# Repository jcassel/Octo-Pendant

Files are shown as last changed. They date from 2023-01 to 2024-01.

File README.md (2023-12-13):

# Octo Pendant
SplashMD_v1 0 0 16
An OctoPrint remote API pendant touch screen. An alternate touch UI for when you are at your printer but want to ensure constant control from OctoPrint. Also includes some utilities to make leveling your printer a little easier. This is really handy for anyone that runs a print farm and wants quick local control of a printer that might be getting run from a multi instance deploy of Octoprint.  It’s so much faster to just tap tap tap for a couple of things than to go to a terminal and access the right instance. One might also find it useful if you are running a headless printer. 

## Features:
* Connects to OctoPrint though API. 
* Displays running Job Status. 
* Allows control of running Job.
  * Can start, pause/resume, and stop loaded files.
* Can control Axis movement.
* Can control Tool and bed temperatures.
* Can run mesh leveling 
* Includes a utility for Manual bed leveling

Currently there are 5 TFT display screens and 3 web configuration screens. 
  TFT Screens include: Main/Monitor, Axis Control, Temperature Control, Leveling Utility, and Info.
  
  Web Configuration Screens include: Configuration Settings, Uploads (File Management), and Firmware Update (OTA)

## Parts

**Required**
* Wemos D1 Mini (4M) [Amazon](https://www.amazon.com/dp/B073CQVFLK/) or [AliExpress](https://www.aliexpress.us/item/3256803535819463.html) or [Tindie](https://www.tindie.com/stores/jcsgotthis/)
* 2.4" Touch TFT (ILI9341) Or equivalent [AliExpress](https://www.aliexpress.us/item/2251832829271342.html) or [Amazon](https://www.amazon.com/dp/B09XHRKFMM) or [Tindie](https://www.tindie.com/stores/jcsgotthis/)
* USB Cable for programing and power 

**nice to have**
* TFT to D1 carrier board [Tindie](https://www.tindie.com/stores/jcsgotthis/)

## Setup
Once you have compiled and downloaded the Firmware, you will be greeted by the touch calibration screen. Go ahead and calibrate it by touching the screen in each corner as indicated by the screen. 

Now you should see a screen with some text and dashes in a bright yellow on a black back ground. Each screen is composed of a background image and a button coordinate system for checking if you touched something interesting on the screen.

At the bottom of the screen you should see text that says "No File Loaded" Touch this. This will take you to the info screen. Its not got anything interesting on it yet but if you get to that screen, you will know things are generally going to work. 

Next you have a choice on how you load the data files. You can either use the "ESP Sketch data upload tool" or you can connect to the device over Wi-Fi and upload the needed files in to 
the spiffs.  

Using the Data upload tool is the quickest if you have it installed. But if you don’t have it installed, its not hard to just upload everything manually. 

To upload the files manually, (my preferred method) do the following. 

* Using your phone or any PC with a Wi-Fi connection, connect to the new Wi-Fi Access point with a name starting with “OctoPendant-New". 
    * Username: admin 
	* Password: Password1 (this is just the default starting point; yes you can change this in the interface.) 
* Once connected, open a browser and connect to this address:
	http://192.168.4.1/spiffs
	You will need to put in the username and password again. 
	
* On this screen you can select files to upload to the device. Best results are if you upload everything in the /data folder in the following order. Note: there are 11 files.
	* style.css
	* scripts.js
	* spiffs.htm (After this the web interface will become a little better)
	Try to refrain from testing hte other menu items, they are not uploaded yet and you will not get what you want.
	* ota.htm
	* mansettings.js
	* mansettings.htm
	* Control1.bmp
  	* ControlMenu.bmp	
   	* Home.bmp
	* Level.bmp
	* Temps.bmp

 * Next you should load up the json region files. These tell the systen where to look for touch screen events. They are also adjustable if you find you want to move things or adjust the touch regions.
   	* ctlmnuscrn.json
	* ctlscrn.json
	* fSrgn.json
	* hscrn.json
	* infoscrn.json
    	* lvlscrn.json
   	* tmpscrn.json

* Now that everything is loaded, you can use the menu in the web interface to go to the Configuration screen. (First menu item at the top of the web page) 
* on this screen, much of it should be self-explanatory but I will go through it in detail. 
    * At the very top is a button to start a scan for available Wi-Fi signals. Push that button to start it. It will return a list of available SSIDs. 
    * Enter in the Wi-Fi SSID for the network your OctoPrint printer is on. 
    * Enter the Password for that SSID (yes, its clear text).
    * Unit Name: This is the network name or host name of the device as it would show up when registering for DNS or DHCP.
    * You can leave the next 2 at default.. They should just work as is, although I have seen good results with 2000 for delay.
    * The Access Password is the password to gain access to the web pages you are using. You can change it. If you forget it, you can change it through serial connection. 
    * HA Unique Id, is specifically for referencing the device in home assistant and even then it's value is only reference. Best practice is to make it match your Unit Name unless you know why you are changing it. 
    * Enable MQTT this will have the device connect to an MQTT broker and send status updates. *Note: This works and will send a general online status to your MQTT broker but I have not really fleshed out any real capabilities in this area yet.)*
    * MQTT Server: The IP Or Full DNS for your MQTT Broker. Cannot be blank if MQTT is enabled. 
    * MQTT UserName: Username for the connection to the MQTT Broker can be blank even if MQTT is enabled.
    * MQTT Password: Password for the connection to the MQTT Broker Can be blank even if MQTT is enabled.
    * MQTT Port: Must be an int value (0 is valid if MQTT is not enabled), typically 1883 
    * OctoPrint URL: The IP or URL for your OctoPrint instance. 
    * OctoPrint Port: The port for your OctoPrint instance. (5000 is the default)
    * OctoPrint APIKey: A key generated by OctoPrint. I strongly suggest you create a user and an API key just for this device. 
    * Enable Mesh Bed Leveling: Only enable this if you have followed the (Mesh Bed leveling guide in the Guides folder)
    * OctoPrint Level GCode File?: This is the path to the gcode file you will create when following the MeshBedLeveling Guide) 
    * Reload Model?: Is only available when Mesh bed leveling is enabled. If checked, and bed leveling is evoked using the green Running man button, if a model other than the "OctoPrint Level GCode file:" is loaded it will reload it after it completes the Mesh level process. 
    * Start Model?: Is is only available when Mesh bed leveling is enabled. If checked, and bed leveling is evoked using the green Running man button and the "Reload Model button is checked as well, OctoPendant will start the print process for the reloaded model. 
    * Bed Volume X in mm: Fill this in with your printers print volume in the X axis.
    * Bed Volume Y in mm: Fill this in with your printers print volume in the Y axis.
    * Bed Volume Offset in mm: This and the 2 other Volume settings are used for manual bed leveling Utility screen where they are used to calculate the locations for the 5 probe/test points are located. Offset is how far from the edge. 
    * Auto Zero X,Y,Z axis on level screen entry: Recommend that this is checked for machines that don’t do mesh leveling. It will ensure marlin knows where it is before you start a manual bed level process. If you do not Zero all, you could crash your hot end. 
    * Time Zone OffSet hrs: Negative or positive number for your time zone. See this [list](https://www.timeanddate.com/time/zones/) for offset values. Do not include the (+) for Positive values.
 
## TFT Screens

**Main/Monitor**
- Using the top 3 buttons you can navigate to 3 other screens. 
    - Axis Control
    - Leveling Util
    - Temperature control
- In the middle of the screen is general information about the gcode model loaded by OctoPrint. 
    -  Status:  General status of the OctoPrint instance (Printer too).
    -  File: Name of the loaded file,  if there is one.
    -  Uploaded: Date time when the loaded file was uploaded.
    -  Print time Est: Estimated duration hh:mm:ss for the loaded file. 
    -  Print Time: How long has the current print been printing hh:mm:ss
    -  Print Time Left: How much time does OctoPrint estimate is left to complete the current print.
- The lower 3 buttons are for control of the loaded model; Start, Pause, and Stop.
- At the bottom center there is a general status Text this will change dependent on the printers overall status as well as if you have given it a command from the above list. Additionally, If you tap this, it will take you to the info screen. 
HomeScreenMD_v1 0 0 16
***

**Axis Control**
- The green left pointing arrow at the top takes you back to the main screen.
- Standard X,Y,Z Axis controls. You can also turn the motors on or off as well as the cooling fan. 
- Home buttons work independently.
- The value buttons can be used to select a value for relative movement of the selected Axis motion button. 
    - OctoPrint will cache the commands so pressing an arrow several times will produce multiple moves. 
    - Note that not all printers will support the Fan on off action. Think Printers that only have one fan like the Kingroon KP3.
AxisControlMD_v1 0 0 16
***

**Temperature Control**
- The green left pointing arrow at the top takes you back to the main screen.
- Control the temperature of the Build plate and the Extruder with ease. Select presets or use incremental values to get it right where you want it. 
    - Top section of the screen is for controlling the Extruder (hot end) temperature.
        - At the top right of the section, the hot end temperatures are shown as [ actual / setting ]
        - Selecting a top value buttons like 1, 5, 10, 20 set the increment for the (+) and (-) Buttons.
        - Selecting bottom values buttons like 170,180,200,230 set the value selected into the set box. 
        - Pushing the Red Power button will turn off the heat to the hot end. 
        - Pushing the Green enter button will set the value selected in the center setting box. 
    - Bottom section of the screen is for controlling the build plate(print bed) temperature.
        - At the top right of the section, the Print bed temperatures are shown as  [ actual / setting ]
        - Selecting a top value buttons like 1, 5, 10, 20 set the increment for the (+) and (-) Buttons.
        - Selecting bottom values buttons like 50, 60, 70, 100 set the value selected into the set box. 
        - Pushing the Red Power button will turn off the heat to the print bed. 
        - Pushing the Green enter button will set the value selected in the center setting box. 
TemperScreenMD_v1 0 0 16

***
**Bed Leveling Utility** (This screen is still in progress)
Controls for doing a manual bed level as well as sending a command set to do a mesh collection process that works with the [Bed Visualizer plugin for Octoprint](https://github.com/jneilliii/OctoPrint-BedLevelVisualizer). 
- The green left pointing arrow at the top takes you back to the main screen.
    - Settings in the Web interface have an effect on how this screen works. See the Setup section and Guides for level Utility usage.  
- Pressing the Home Button on this screen will home X,Y,Z axis *(see web interface for settings related to homing settings)*
- Pressing one of the 5 dots on the bed will send the print head to that position on your build plat for paper style leveling. Z height will be absolute zero. *(Be sure you have homed your machine prior to using this screen.)*  
- Pressing the Running man on the left (white) will run the mesh collection process and wait. *(see web interface for settings related to mesh leveling settings)*
- Pressing the Running man on the right (green) will run the mesh collection process and reload the current model and start it. *(see web interface for settings related to mesh leveling settings)*

LevelMD_v1 0 0 16

***
**Pendant Info Screen**
This screen shows Connection details for the Pendant. Also has a reset button at the bottom. I plan on adding more here as it makes sense.

InfoScreenMD_v1 0 0 16
***

## Carrier Board
I created a Carrier board for connecting the D1 mini to the 2.4" TFT(Touch) board. Note that the TFT has an SD Card slot on it but it is not wired up. Yes it looks like it is.. The posts are there for support. You can solder these boards together and that saves a lot of space but be careful, the SD card cover is right over 2 of the pins of the D1 mini. 

grbl files are available as part of the repo. Also boards are available from my [Tindie](https://www.tindie.com/stores/jcsgotthis/) Store along with other related items.

D1 mini mounted on carrier*(Note that I have a small Cap to help stabilize power for the board. It’s not really needed.):

TFT-esp8266CarrierBoard_D1

Carrier without D1 mini:

TFT-esp8266CarrierBoard_Back

TFT mount side:

TFT-esp8266CarrierBoard_Front

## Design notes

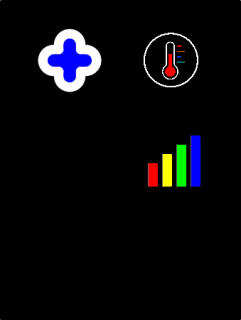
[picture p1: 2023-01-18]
ControlMenu.bmp

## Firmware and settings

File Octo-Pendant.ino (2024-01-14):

#include <ArduinoJson.h> 
#include <ESP8266WiFi.h>
#include <ESP8266WebServer.h>
#include <ESP8266mDNS.h>
#include <Bounce2.h>
#include <NTPClient.h>
#include <MQTT.h>
#include "TimeRelease.h"
#include "ActionRegion.h"
#include <OctoPrintAPI.h> //would be best to use this fork: https://github.com/jcassel/OctoPrintAPI but the parent at https://github.com/chunkysteveo/OctoPrintAPI should work as well. 
#include <SPI.h>
#include <TFT_eSPI.h>      // Hardware-specific library
#include "globals.h"
#include "MQTTControl.h"
#include <ESP8266WebOTA.h> //Lib is here: https://github.com/jcassel/ESP8266WebOTA
#include "FS.h"
#define FS_NO_GLOBALS
#include "webPages.h"

#include <Time.h>         //We will need these two just to do some rough time math on the timestamps we get
#include <TimeLib.h>

void setup() {
  Serial.begin(74880);
  #ifdef _debugopra
  Serial.println("Begin Setup");
  
  struct  rst_info  *rtc_info = system_get_rst_info();
  os_printf("reset  reason: %x\n",  rtc_info->reason);
  Serial.println(rtc_info->reason);
   if (rtc_info->reason ==  REASON_WDT_RST  || rtc_info->reason ==  REASON_EXCEPTION_RST  || rtc_info->reason ==  REASON_SOFT_WDT_RST)  {
     if (rtc_info->reason ==  REASON_EXCEPTION_RST) {
       os_printf("Fatal exception (%d):\n", rtc_info->exccause);
      }
      //The address of  the last  crash is  printed,  which is  used  to debug garbled output.
     os_printf("epc1=0x%08x,  epc2=0x%08x,  epc3=0x%08x,  excvaddr=0x%08x,depc=0x%08x\n",rtc_info->epc1,  rtc_info->epc2, rtc_info->epc3, rtc_info->excvaddr,  rtc_info->depc);
   }
  #endif
  
  #ifdef _OctoAPIDebug
  api._debug = true;
  #endif
   
  InitStorageSetup(); //start spiffs
  SetupWifi();
  
  loadSettingsConfig();
  loadMQTTConfig();

  Serial.println("begin init pages");
  initialisePages();
  Serial.println("end init pages");
  webServer.begin();
  Serial.println("end webserver.begin");
  
  ESP8266webota.init(&webServer,"/update","admin",wificonfig.apPassword);
  ESP8266webota.filePathOverRide = "/ota.htm";
  Serial.println("end webota");

  if(mqttConfig.MQTTEN){
    ReconnectMQTT.set(10000UL); //check in 10sec on startup.
    mqttClient.begin(mqttConfig.MQTTSrvIp, MQTT);
    mqttClient.onMessage(mqttMessageReceived);
    mqttStatusInerval.set(mqttConfig.StatusIntervalSec * 1000);
  }
  Serial.println("end MQTT");
  api.init(net, settingsConfig.OPURI, settingsConfig.OPPort, settingsConfig.OPAK);
  Serial.println("end OctoprintAPI");
  tft.init();
  Serial.println("end TFT init");
  
  pinMode(TFT_LED, OUTPUT);
  digitalWrite(TFT_LED, HIGH);    // HIGH to Turn on; 
  
  #ifdef _debugopra
  Serial.println("tft.init():complete");
  #endif
  
  // Set the rotation before we calibrate
  tft.setRotation(0);
  #ifdef _debugopra
  Serial.println("tft.setRotation(2):complete");
  #endif
  
  // Calibrate the touch screen and retrieve the scaling factors
  touch_calibrate();
  #ifdef _debugopra
  Serial.println("touch_calibrate():complete");
  #endif
  
  initHomeScreen();

  //set min polling time these are low so that they get run first time quickly.
  PollPrinterStats.set(100ul);
  PollPrinterJobInfo.set(100ul);
  UpdateCurrentScreen.set(10ul);
  PollConnectionInfo.set(30ul);
  PollAxisInfo.set(20ul);
  PollOPOnline.set(500ul);
  delay(100);

}

void loop() {
  
  
  CheckWifi();
  if(mqttConfig.MQTTEN){
    if(mqttStatusInerval.check()){
      MQTTPushStatus = true;
      mqttStatusInerval.set(mqttConfig.StatusIntervalSec * 1000);
    }
  
    if(!InAPMode && CheckMQTTConnection()){
      mqttClient.loop();
      if(MQTTPushStatus == true){
        MQTTPushStatus = false;
        MQTTStatus();
      }
    }
  }

  webServer.handleClient();
  doPrinterAutoConnect();
  CheckSerialCommands();
  
  CheckTouch();

  if(UpdateCurrentScreen.check()){
    ProcessScreenData();
    UpdateCurrentScreen.set(UpdateCurrentScreenPollInterval); //set interval for next update of screen.
  }
  
  if(doWiFiScan){
    doWiFiScan = false;
    int n = WiFi.scanNetworks();
    storeWifiScanResult(n);
  }
  
  isOctoPrintOnline(); //not really doing much but will populate the version info struct

  
} //end loop

void doPrinterAutoConnect(){
  #ifdef _debugopra
    Serial.println("Check AutoConnect");
  #endif
  
  if(settingsConfig.ACONP){
    apigetConnectionInfo();
    #ifdef _debugopra
      Serial.println("AutoConnect: true");
      Serial.print("Current State:");Serial.println(currentCon.state);
      Serial.print("Current Printer State:");Serial.println(api.printerStats.printerState);
      
    #endif
    
    if(currentCon.state != "Operational"){
      #ifdef _debugopra
      Serial.println("Checking to see if a connection should be tried.");
      #endif
      
      if(currentCon.state != "Opening serial connection" && currentCon.state != "Connection request sent"){
        #ifdef _debugopra
          Serial.println("tring to connect.");
        #endif
        //Try to reconnect to settingsConfig.PProfile
        String command = "{\"command\":\"connect\",\"autoconnect\": true,\"printerProfile\": \""+ String(settingsConfig.PProfile) + "\"}";
        api.sendPostToOctoPrint("/api/connection",command.c_str());
        currentCon.state = "Connection request sent"; //Set this so that we dont spam Ocoprint with connection commands. It will update with the next status request.
        //should set check interval to maybe 1 sec. for a few iterations. 
      }else{
        #ifdef _debugopra
          Serial.println("No need to try to connect.");
        #endif
      }
    }
  }
}



bool CheckTouch(){
  // Pressed will be set true is there is a valid touch on the screen
  uint16_t t_x = 0, t_y = 0; // To store the touch coordinates
  
  bool pressed = tft.getTouch(&t_x, &t_y);
  
  if(pressed){
    //Serial.println("pressed");
  }

  
  bool wasPushed = false;
  if(currentScreen == 0){
    wasPushed = hmRgnPushed(t_x,t_y);
  }else if(currentScreen == 1){
    wasPushed = ctlRgnPushed(t_x,t_y);
    //wasPushed = ActionRegionPushed(t_x,t_y,ctlscrnRgns,ctlscrnRgnsSize);
  }else if (currentScreen == 2){
    wasPushed = tmpRgnPushed(t_x,t_y)  ;
  }else if (currentScreen == 3){
    wasPushed = lvlRgnPushed(t_x,t_y);
  }else if (currentScreen == 4){
    //ActionRegionPushed(t_x,t_y,infoScrnARgn,infoScrnRgnSize);
    wasPushed = infoRgnPushed(t_x,t_y);
  }else if(currentScreen == 5){
    wasPushed = CtlMnuRgnPushed(t_x,t_y);
  }else if(currentScreen == 6){
    wasPushed = filCtlRgnPushed(t_x,t_y);
  }
  
  
  if(t_x != 0 ||t_y != 0){

    #ifdef _debugTouch
    
    //Serial.print("Pressure = ");
    //Serial.print(p.z);
    Serial.print("x = ");
    Serial.print(t_x);
    Serial.print(", y = ");
    Serial.print(t_y);
    Serial.println();
    #endif
  }

  return wasPushed;
  
  
}


void ProcessScreenData(){
  
  if(currentScreen ==0){
    setHomeText(false);
  } else if (currentScreen == 1){
    setControlScreenText(); 
  }else if (currentScreen == 2){
    setTemperatureScreenText();
  }else if (currentScreen == 3){
    setLevelScreenText();
  }else if (currentScreen == 4){
    setInfoScreenText();
  }else if (currentScreen == 5){
    setCtlMnuScreenText();
  }else if (currentScreen == 6){
    setfilCtlScreenText();
  }

  //checkon background Processes
  checkRunningMeshCollection(); //dont care what screen you are on.. This needs to continue to work after you leave the screen.
  
}




void PrintNetStat(){
  Serial.print("Is Wifi Connected: ");
  Serial.println();
  if (isWiFiConnected(false)){
    Serial.println("yes");
    Serial.print("IP:");
    Serial.println(WiFi.localIP());
    
    Serial.print("SubNet:");
    Serial.println(WiFi.subnetMask());

    Serial.print("Gateway:");
    Serial.println(WiFi.gatewayIP());
    //would like to add other info here. Things like gateway and dns server and Maybe MQTT info
  }else{
    Serial.println("No");
  }
  
}

void CheckSerialCommands(){
  if (Serial.available())
  {
    String buf = Serial.readStringUntil('\n');
    buf.trim();
    #ifdef _debugopra
    Serial.print("buf:");Serial.println(buf);
    #endif
    
    int sepPos = buf.indexOf(" ");
    String command ="";
    String value = "";
    
    if(sepPos){
      command = buf.substring(0,sepPos);
      value = buf.substring(sepPos+1);;
      #ifdef _debugopra
        Serial.print("command:");Serial.print("[");Serial.print(command);Serial.println("]");
        Serial.print("value:");Serial.print("[");Serial.print(value);Serial.println("]");
      #endif
    }else{
      command = buf;
      #ifdef _debugopra
        Serial.print("command:");Serial.print("[");Serial.print(command);Serial.println("]");
      #endif
    }
    
    if (command == "help"){
      Serial.println("Avalible commands: (all commands should end with a space when there are no parameters)");
      Serial.println("setssid [param]; sets the wifi SSID to the param value");
      Serial.println("setpassword [param]; sets the wifi password to the param value");
      Serial.println("setwifimode [param]; sets the wifi Mode for next startup to the param value");
      Serial.println("sethostname [param]; sets the wifi password to the param value");
      Serial.println("setappassword [param]; sets the wifi password to the param value");
      Serial.println("setattempts [param]; sets the wifi password to the param value");
      Serial.println("setattemptdelay [param]; sets the wifi password to the param value");
      Serial.println("savesettings ; applys any values updates to permenent settings");
      Serial.println("restart ; restarts the pendant instantly");
      Serial.println("netstat ; returns network info about the wifi connection");
      Serial.println("tcal ; begins a touch screen calabration");
      Serial.println("settooltemp [param]; sends command to Octoprint to set hot end temperature to param value (number in deg c)");
      Serial.println("setbedtemp [param]; sends command to Octoprint to set Bed temperature to param value (number in deg c)");
      Serial.println("setpoll [param]; sets interval to poll the Octoprint instance for status (number in ms) ");
      #ifdef _debugopra
      Serial.println("font [param]; Sets font number for system display [experemental could be fatal]");
      Serial.println("getsrgn [param]; gets the current screens region info for the supplied param(number)");
      #endif
    }
    else if (command == "setssid"){strlcpy(wificonfig.ssid,value.c_str(),sizeof(wificonfig.ssid));Serial.println("SSID Set");}
    else if (command == "setpassword"){strlcpy(wificonfig.password,value.c_str(),sizeof(wificonfig.password));Serial.println("Password Set");}
    else if (command == "setwifimode"){strlcpy(wificonfig.wifimode,value.c_str(),sizeof(wificonfig.wifimode));Serial.println("WiFiMode Set");}
    else if (command == "sethostname"){ strlcpy(wificonfig.hostname,value.c_str(),sizeof(wificonfig.hostname));Serial.println("HostName Set");}
    else if (command == "setappassword"){strlcpy(wificonfig.apPassword,value.c_str(), sizeof(wificonfig.apPassword));Serial.println("AP Password Set");}
    else if (command == "setattempts"){wificonfig.attempts = value.toInt();Serial.println("Number of connection attempts Set");}
    else if (command == "setattemptdelay"){wificonfig.attemptdelay = value.toInt();Serial.println("Connection Attempt delay Set");}
    else if (command == "savesettings"){saveWifiConfig(wificonfig);Serial.println("Configuration saved. Restart to apply.");}
    else if (command == "restart" || command == "reset" || command == "reboot"){Serial.println("[WARNING]: Restarting");ESP.restart();}
    else if (command == "netstat"){PrintNetStat();}
    else if (command == "RunMeshCollection"){if (value=="true" || value=="1"){RunMeshCollection(true);}else{RunMeshCollection(false);}}
    else if (command == "tcal"){REPEAT_CAL=true; touch_calibrate(); initControlScreen();}
    else if (command == "settooltemp"){api.octoPrintSetTool0Temperature(value.toInt());}
    else if (command == "setbedtemp"){api.octoPrintSetBedTemperature(value.toInt());}
    else if (command == "setpoll"){UpdateCurrentScreenPollInterval = value.toInt();}
    else if (command == "spiffstat"){Serial.print("Space Left Bytes:");Serial.println(SpaceLeft());}
    
  }
}

void touch_calibrate()
{
  uint16_t calData[5];
  uint8_t calDataOK = 0;

  // check file system exists
  if (!SPIFFS.begin()) {
    #ifdef _debugopra
    Serial.println("Formating file system");
    #endif
    
    SPIFFS.format();
    SPIFFS.begin();
    
    #ifdef _debugopra
    Serial.println("SPIFFs Ready");
    #endif
  }else{
    #ifdef _debugopra
    Serial.println("SPIFFs Ready");
    #endif
  }

  // check if calibration file exists and size is correct
  if (SPIFFS.exists(CALIBRATION_FILE)) {
    if (REPEAT_CAL )
    {
      // Delete if we want to re-calibrate
      SPIFFS.remove(CALIBRATION_FILE);
    }
    else
    {
      File f = SPIFFS.open(CALIBRATION_FILE, "r");
      if (f) {
        if (f.readBytes((char *)calData, 14) == 14)
          calDataOK = 1;
        f.close();
      }
    }
  }else{
    #ifdef _debugopra
    Serial.println("Calabration File Exists");
    #endif
  }

  if (calDataOK && !REPEAT_CAL) {
    #ifdef _debugopra
    Serial.println("Cal Data Valid");
    #endif
    // calibration data valid
    tft.setTouch(calData);
  } else {
    #ifdef _debugopra
    Serial.println("Cal data not valid so recalibrate");
    #endif
    // data not valid so recalibrate
    tft.fillScreen(TFT_BLACK);
    tft.setCursor(20, 0);
    tft.setTextFont(2);
    tft.setTextSize(1);
    tft.setTextColor(TFT_WHITE, TFT_BLACK);

    tft.println("Touch corners as indicated");

    tft.setTextFont(1);
    tft.println();

    if (REPEAT_CAL) {
      tft.setTextColor(TFT_RED, TFT_BLACK);
      tft.println("Set REPEAT_CAL to false to stop this running again!");
    }

    tft.calibrateTouch(calData, TFT_MAGENTA, TFT_BLACK, 15);

    tft.setTextColor(TFT_GREEN, TFT_BLACK);
    tft.println("Calibration complete!");

    // store data
    File f = SPIFFS.open(CALIBRATION_FILE, "w");
    if (f) {
      f.write((const unsigned char *)calData, 14);
      f.close();
    }
  }
}


/*
 * This is to create a way to throttle the requests 
 * Starting at 3 sec. seems to work well. But in some 
 * cases you may want to make the direct call and 
 * reset the runningMillis if you want to show 
 * something happened with an imediate update.
 */

String previousPath;
bool runningMeshCollection;
bool mcUseSettings = false;


bool apigetPrintJob(){
    if(PollPrinterJobInfo.check()){
      api.getPrintJob();
      #ifdef _debugopra
      Serial.println("Print Job info updated");
      #endif
      PollPrinterJobInfo.set(PollPrinterJobInfoInterval);
      return true;
    }
  return false;
}

bool apigetPrintStats(){
  if(PollPrinterStats.check()){
    api.getPrinterStatistics();
    #ifdef _debugopra
    Serial.println("Printer Stats updated");
    #endif
    PollPrinterStats.set(PollPrinterStatsInterval);
    return true;
  }
  return false;
}

bool apigetConnectionInfo(){
  if(PollConnectionInfo.check()){
    #ifdef _debugopra
    Serial.println("Printer Connection info updated>>>>>>>>>>>>>>>>>>>>>>>>>>>>>>>>>>>>>>>>>>>>>>>>>>>>>>>>>>>>");
    #endif
    PollConnectionInfo.set(PollConnectionInfoInterval);
    return getPrinterConnectionInfo();
  }
  return false;
}

//  this is here and not in the Level Screen purposfully. Its something that runs
//  even if you leave the screen and needs to be monitored for completion. 
void checkRunningMeshCollection(){
  if(runningMeshCollection){
    if (apigetPrintJob() && api.printJob.printerState != "Printing"){ //only check when we get an update of info.
      #ifdef _debugopra
        Serial.println("meshCollection is done running");  
      #endif
      if(mcUseSettings && settingsConfig.OPReload){
        api.octoPrintFileSelect("/"+previousPath);
        if(settingsConfig.OPStart){
          api.octoPrintJobStart();
        }
        
      }
      runningMeshCollection = false;
    }else{
      #ifdef _debugopra
        Serial.println("meshCollection is still running");
      #endif
    }
  }else{
    #ifdef _debugopra
      if(runningMeshCollection){Serial.print("Running Mesh Collection!");}
    #endif
  }
}

struct AxisInfo{int X; int Y; int Z;};
AxisInfo axisInfo;



bool getAxisPostionInfo(){
  
  if(PollAxisInfo.check()){
    String response = api.getOctoprintEndpointResults(OCTOPENDENT_API_URL);
    StaticJsonDocument<512> root;
    
    DeserializationError  error = deserializeJson(root, response);
    if (!error) {
      axisInfo.X = root["Axis"]["X"];
      axisInfo.Y = root["Axis"]["Y"];
      axisInfo.Z = root["Axis"]["Z"];

      #ifdef _debugopra
        Serial.print("axisInfo.X:"); Serial.println(axisInfo.X); Serial.print("axisInfo.Y:"); Serial.println(axisInfo.Y); Serial.print("axisInfo.Z:"); Serial.println(axisInfo.Z);
      #endif
      
      PollAxisInfo.set(PollAxisInfoInderval);
      return true;
    }else{
      #ifdef _debugopra
        Serial.println("Error getting Printer Axis position details.\n");
        if(error){ Serial.println("Deserialization error in getAxisPostionInfo");}
        
        Serial.println("Possible octoprint api error in getAxisPostionInfo");
        Serial.print("Status Code:");
        Serial.print("Status Code:");
        Serial.println(api.httpStatusCode);
        Serial.println("Response Body:");
        Serial.println(api.httpErrorBody);
      #endif 
    }
  }
  return false;
}

bool getPrinterConnectionInfo(){
  //call generic endpoint method...
  String response = api.getOctoprintEndpointResults("connection");
  StaticJsonDocument<2048> root; //seems to be pretty large for a PC based solution. 
  DeserializationError  error = deserializeJson(root, response);
  if (!error) {
    currentCon.state = (const char *)root["current"]["state"]; // "Opening serial connection","Operational","Closed"
    currentCon.profileId = (const char *)root["current"]["printerProfile"]; //"_default" is if no profile is selected. It maybe the only profile in the system. 
    currentCon.port = (const char *)root["current"]["port"];
    currentCon.baudrate = root["current"]["baudrate"];
    
    #ifdef _debugopra
    Serial.print("currentCon.state:");
    Serial.println(currentCon.state);

    Serial.print("currentCon.profileId:");
    Serial.println(currentCon.profileId);

    Serial.print("currentCon.port:");
    Serial.println(currentCon.port);
    #endif
    
    return true;
  }else{
    
    Serial.print("deserializeJson() failed: getPrinterConnectionInfo()");
    Serial.println(error.c_str());
    
    
    Serial.println("Error getting Printer Serial Conneciton details.\nLikely the response is too large for the buffer.\nMaybe there are too many ports listed.\nUse the black list in OctoPrint's Serial Settings to remove all ports that do not matter.");
    Serial.println("Response object:");
    Serial.println(response);
    
    Serial.print("Status Code:");
    Serial.println(api.httpStatusCode);
    Serial.println("Response Body:");
    Serial.println(api.httpErrorBody);
    
  }
  return false;
}

bool OctoPrintOnline = true;
bool isOctoPrintOnline(){
  if(PollOPOnline.check()){
    OctoPrintOnline = api.getOctoprintVersion();
    PollOPOnline.set(PollOPOnlineInterval);
  }
  return OctoPrintOnline;
}

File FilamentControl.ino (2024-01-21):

#define filCtlRgnSize  15
ActionRegion filCtlARgn[filCtlRgnSize];

#define returnRgn 0
#define automateRgn 1
#define eHeatOffRgn 2
#define heat1Rgn 3
#define heat2Rgn 4
#define heat3Rgn 5
#define heat4Rgn 6
#define UnldbtnRgn 7
#define Unl1Rgn 8
#define Unl2Rgn 9
#define Unl3Rgn 10
#define Unl4Rgn 11
#define LdbtnRgn 12
#define curEvalsRgn 13
#define curEDisRgn 14

int unloadLen = 400; //should be a setting. 

bool rgnsLoaded = false;
bool filCtlRgnPushed(int x, int y){
  if(rgnsLoaded){
    for (uint8_t rgn = 0; rgn < filCtlRgnSize; rgn++) {   
      if(filCtlARgn[rgn].contains(x,y,true)){//true here causes the hooked event to fire if this return true. 
        #ifdef _debugopra
        Serial.println(rgn); //finished test event text assertion
        #endif
        return true;
      }
    }
  }
  return false;
}

void filCtlARgn_R(){ //0
  #ifdef _debugopra
  Serial.println("filCtlRgnAction_hm");
  #endif
  currentScreen = 5;
  initCtlMnu();
}

void filCtlARgn_A(){ //1
  #ifdef _debugopra
  Serial.println("filCtlARgn_1");
  #endif
  char commandData[100];
  String commandString = "M600 B10 U400 L100 X"+String(settingsConfig.BVX-settingsConfig.BVO) +" Y"+String(settingsConfig.BVO)+ " Z40";
  Serial.print("FilamentOut Command:");
  Serial.println(commandString);
  //"M600 B10 U400 L100 X[front] Y[right] Z40[Relative]
  strlcpy(commandData, commandString.c_str(), sizeof(commandData));
  api.octoPrintPrinterCommand(commandData);
  
}


void filCtlARgn_E(){ //Extruder heat off
  #ifdef _debugopra
  Serial.println("filCtlARgn_E");
  #endif
  api.octoPrintSetTool0Temperature(0);
}

void filCtlARgn_H1(){ 
  #ifdef _debugopra
  Serial.println("filCtlARgn_H1");
  #endif
  api.octoPrintSetTool0Temperature(170);
}

void filCtlARgn_H2(){ 
  #ifdef _debugopra
  Serial.println("filCtlARgn_H2");
  #endif
  api.octoPrintSetTool0Temperature(180);
}


void filCtlARgn_H3(){ 
  #ifdef _debugopra
  Serial.println("filCtlARgn_H3");
  #endif
  api.octoPrintSetTool0Temperature(200);
}

void filCtlARgn_H4(){ 
  #ifdef _debugopra
  Serial.println("filCtlARgn_H4");
  #endif
  api.octoPrintSetTool0Temperature(230);
  
}

void filCtlARgn_Ulb(){ //unload button Up Arrow
  #ifdef _debugopra
  Serial.println("filCtlARgn_Ulb");
  #endif
  Serial.print("Retracting Filament: ");Serial.print(unloadLen);Serial.println("mm");
  String commands = "{\"commands\": [\"G91\",\"M83\",\"G1 E-"+ String(unloadLen) +" F300\",\"M82\",\"M90\"]}"; 
  api.sendPostToOctoPrint("/api/printer/command",commands.c_str());
  setfilCtlScreenText();
  
}

void filCtlARgn_Ul1(){ 
  #ifdef _debugopra
  Serial.println("filCtlARgn_Ul1");
  #endif
  unloadLen = 10;
  setfilCtlScreenText();
}

void filCtlARgn_Ul2(){ 
  #ifdef _debugopra
  Serial.println("filCtlARgn_Ul2");
  #endif
  unloadLen = 100;
  setfilCtlScreenText();
}

void filCtlARgn_Ul3(){ 
  #ifdef _debugopra
  Serial.println("filCtlARgn_Ul3");
  #endif
  unloadLen = 50;
  setfilCtlScreenText();
}

void filCtlARgn_Ul4(){ 
  #ifdef _debugopra
  Serial.println("filCtlARgn_Ul4");
  #endif
  unloadLen = 200;
  setfilCtlScreenText();
}

void filCtlARgn_Lb(){ //load button Down arrow
  #ifdef _debugopra
  Serial.println("filCtlARgn_Lb");
  #endif
  Serial.print("Extruding Filament: ");Serial.print(unloadLen);Serial.println("mm");
  String commands = "{\"commands\": [\"G91\",\"M83\",\"G1 E"+ String(unloadLen) +" F300\",\"M82\",\"M90\"]}"; 
  api.sendPostToOctoPrint("/api/printer/command",commands.c_str());
}


bool loadFilamentScreenRgns(){
  const char* sourceFile = "/fSrgn.json";
  bool fileExists = SPIFFS.exists(sourceFile);
  
  char tmpSRgn[13];   
  strlcpy(tmpSRgn, "001001065050", 13); //<< plug in the same value you would have from your file if you want to change this at this level.
  Region tmpRgn = getRegionFromString(tmpSRgn);
  filCtlARgn[returnRgn].TextRgn = false;
  filCtlARgn[returnRgn].init(tmpRgn);
    
  if(!fileExists){
    #ifdef _debugopra
      Serial.println("[WARNING]: Config file:");Serial.print(sourceFile);Serial.println(" not found");
    #endif
  }
  #ifdef _debugopra
  Serial.print("Loading:");Serial.println(sourceFile);
  #endif
  File configfile = SPIFFS.open(sourceFile,"r");
  DynamicJsonDocument doc(1024);  
  DeserializationError error = deserializeJson(doc, configfile);
  
  if (error){Serial.println("[ERROR]: deserializeJson() error in lvlscrn.json");Serial.println(error.c_str());}

  #ifdef _debugopra
    Serial.println("Rendering Screen Regions");
  #endif
  
 
    //Return
    strlcpy(tmpSRgn, doc["R"] | "001001065050", 13);
    tmpRgn = getRegionFromString(tmpSRgn);
    filCtlARgn[returnRgn].init(tmpRgn);
    filCtlARgn[returnRgn].setReleaseAction(filCtlARgn_R);
    
    //Automate 
    strlcpy(tmpSRgn, doc["A"] | "180001065050", 13);
    tmpRgn = getRegionFromString(tmpSRgn);
    filCtlARgn[automateRgn].init(tmpRgn);
    filCtlARgn[automateRgn].setReleaseAction(filCtlARgn_A);
    
    //eHeatOff
    strlcpy(tmpSRgn, doc["E"] | "190070050040", 13);
    tmpRgn = getRegionFromString(tmpSRgn);
    filCtlARgn[eHeatOffRgn].init(tmpRgn);
    filCtlARgn[eHeatOffRgn].setReleaseAction(filCtlARgn_E);
    
    //Heat1
    strlcpy(tmpSRgn, doc["H1"] | "010115050035", 13);
    tmpRgn = getRegionFromString(tmpSRgn);
    filCtlARgn[heat1Rgn].init(tmpRgn);
    filCtlARgn[heat1Rgn].setReleaseAction(filCtlARgn_H1);
  
    //Heat2
    strlcpy(tmpSRgn, doc["H2"] | "070115050035", 13);
     tmpRgn = getRegionFromString(tmpSRgn);
    filCtlARgn[heat2Rgn].init(tmpRgn);
    filCtlARgn[heat2Rgn].setReleaseAction(filCtlARgn_H2);
  
    //Heat3
    strlcpy(tmpSRgn, doc["H3"] | "125115050035", 13);
     tmpRgn = getRegionFromString(tmpSRgn);
    filCtlARgn[heat3Rgn].init(tmpRgn);
    filCtlARgn[heat3Rgn].setReleaseAction(filCtlARgn_H3);
  
    //Heat4
    strlcpy(tmpSRgn, doc["H4"] | "190115050035", 13);
     tmpRgn = getRegionFromString(tmpSRgn);
    filCtlARgn[heat4Rgn].init(tmpRgn);   
    filCtlARgn[heat4Rgn].setReleaseAction(filCtlARgn_H4);

    //unloadbtn (up arrow)
    strlcpy(tmpSRgn, doc["Ulb"] | "160170060050", 13);
     tmpRgn = getRegionFromString(tmpSRgn);
    filCtlARgn[UnldbtnRgn].init(tmpRgn);   
    filCtlARgn[UnldbtnRgn].setReleaseAction(filCtlARgn_Ulb);

    //load heat 1
    strlcpy(tmpSRgn, doc["Ul1"] | "036198050035", 13);
     tmpRgn = getRegionFromString(tmpSRgn);
    filCtlARgn[Unl1Rgn].init(tmpRgn);       
    filCtlARgn[Unl1Rgn].setReleaseAction(filCtlARgn_Ul1);
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

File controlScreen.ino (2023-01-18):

/*
 * Control Screen 
 */
#define ctlscrnRgnsSize 17
ActionRegion ctlscrnRgns[ctlscrnRgnsSize]; //control screen

#define CTLR    0
#define YU   1
#define ZU   2
#define XL  3
#define XYH  4
#define XR  5
#define ZH   6
#define YD  7
#define ZD  8
#define MVP1  9
#define MV1   10
#define MV10   11
#define MV20   12
#define FON   13
#define FOff  14
#define MOff  15
#define ctl_SV 16

int ctltxt = 100;

bool ctlRgnPushed(int x, int y){
  for (uint8_t rgn = 0; rgn < ctlscrnRgnsSize; rgn++) {   
    if(ctlscrnRgns[rgn].contains(x,y,true)){//true here causes the hooked event to fire if this return true. 
      #ifdef _debugopra
      Serial.println(rgn); //finished test event text assertion
      #endif
      return true;
    }
  }
  return false;
}


void setControlScreenText(){
  //ctl_SV
  //lvlscrnRgns[BCV].displayText(&tft,tempDisplayBed,TFT_BLACK,TFT_YELLOW); //set text on screen for temp values of bed
  
  //tft.fillRect(ctltxtRegion[0], ctltxtRegion[1], ctltxtRegion[3], ctltxtRegion[2], TFT_BLACK);
  //tft.setTextDatum(TL_DATUM);        // Use top left corner as text coord datum
  //tft.setTextColor(TFT_YELLOW);     // Set the font colour
  // Draw the string, the value returned is the width in pixels
  #ifdef _debugopra
  Serial.print("ctlMvVal: ");
  Serial.println(ctltxt);
  #endif 
  
  String displayValue = String(ctltxt*0.1);
  if(ctltxt == 1){
    displayValue = "0.1";
  }else{
    displayValue = displayValue.substring(0,displayValue.length()-3);
  }

  ctlscrnRgns[ctl_SV].displayText(&tft,displayValue,TFT_BLACK,TFT_YELLOW);
  //ctltxtRegion[3] = tft.drawString(displayValue,ctltxtRegion[0], ctltxtRegion[1]);
  #ifdef _debugopra
  ctlscrnRgns[ctl_SV].drawRegion(&tft,TFT_YELLOW); // turn this on to debug visually the regions. draws a box around the button 
  //tft.drawRect(ctltxtRegion[0], ctltxtRegion[1], ctltxtRegion[3], ctltxtRegion[2], TFT_YELLOW);
  #endif

  if(needsHoming()){
    motionDisabled = true;
    tft.fillCircle(ctlscrnRgns[XYH].region.x+(ctlscrnRgns[XYH].region.w/2),ctlscrnRgns[XYH].region.y+(ctlscrnRgns[XYH].region.h/2),6,TFT_YELLOW);
    tft.fillCircle(ctlscrnRgns[ZH].region.x+(ctlscrnRgns[ZH].region.w/2),ctlscrnRgns[ZH].region.y+(ctlscrnRgns[ZH].region.h/2),6,TFT_YELLOW);
    tft.fillCircle(ctlscrnRgns[ZU].region.x+(ctlscrnRgns[ZU].region.w/2),ctlscrnRgns[ZU].region.y+(ctlscrnRgns[ZU].region.h/2),3,TFT_RED);
    tft.fillCircle(ctlscrnRgns[ZD].region.x+(ctlscrnRgns[ZD].region.w/2),ctlscrnRgns[ZD].region.y+(ctlscrnRgns[ZD].region.h/2),3,TFT_RED);
    
    tft.fillCircle(ctlscrnRgns[YU].region.x+(ctlscrnRgns[YU].region.w/2),ctlscrnRgns[YU].region.y+(ctlscrnRgns[YU].region.h/2),3,TFT_RED);
    tft.fillCircle(ctlscrnRgns[YD].region.x+(ctlscrnRgns[YD].region.w/2),ctlscrnRgns[YD].region.y+(ctlscrnRgns[YD].region.h/2),3,TFT_RED);
    tft.fillCircle(ctlscrnRgns[XL].region.x+(ctlscrnRgns[XL].region.w/2),ctlscrnRgns[XL].region.y+(ctlscrnRgns[XL].region.h/2),3,TFT_RED);
    tft.fillCircle(ctlscrnRgns[XR].region.x+(ctlscrnRgns[XR].region.w/2),ctlscrnRgns[XR].region.y+(ctlscrnRgns[XR].region.h/2),3,TFT_RED);
  }else{
    motionDisabled = false;
    tft.fillCircle(ctlscrnRgns[XYH].region.x+(ctlscrnRgns[XYH].region.w/2),ctlscrnRgns[XYH].region.y+(ctlscrnRgns[XYH].region.h/2),6,TFT_BLACK); //this should remove the red dot if you home manually
    tft.fillCircle(ctlscrnRgns[ZH].region.x+(ctlscrnRgns[ZH].region.w/2),ctlscrnRgns[ZH].region.y+(ctlscrnRgns[ZH].region.h/2),6,TFT_BLACK); //this should remove the red dot if you home manually
    tft.fillCircle(ctlscrnRgns[ZU].region.x+(ctlscrnRgns[ZU].region.w/2),ctlscrnRgns[ZU].region.y+(ctlscrnRgns[ZU].region.h/2),3,TFT_BLACK);
    tft.fillCircle(ctlscrnRgns[ZD].region.x+(ctlscrnRgns[ZD].region.w/2),ctlscrnRgns[ZD].region.y+(ctlscrnRgns[ZD].region.h/2),3,TFT_BLACK);
    tft.fillCircle(ctlscrnRgns[YU].region.x+(ctlscrnRgns[YU].region.w/2),ctlscrnRgns[YU].region.y+(ctlscrnRgns[YU].region.h/2),3,TFT_BLACK);
    tft.fillCircle(ctlscrnRgns[YD].region.x+(ctlscrnRgns[YD].region.w/2),ctlscrnRgns[YD].region.y+(ctlscrnRgns[YD].region.h/2),3,TFT_BLACK);
    tft.fillCircle(ctlscrnRgns[XL].region.x+(ctlscrnRgns[XL].region.w/2),ctlscrnRgns[XL].region.y+(ctlscrnRgns[XL].region.h/2),3,TFT_BLACK);
    tft.fillCircle(ctlscrnRgns[XR].region.x+(ctlscrnRgns[XR].region.w/2),ctlscrnRgns[XR].region.y+(ctlscrnRgns[XR].region.h/2),3,TFT_BLACK);
  }


  
}


void ctlRgnAction_YU(){
  #ifdef _debugopra
  Serial.println("ctlRgnAction_YU");
  #endif
  if(!motionDisabled){
    api.octoPrintPrintHeadRelativeJog(0,(ctltxt*0.1),0,0);//x,y,z,f(speed)
  }
}

void ctlRgnAction_ZU(){
  #ifdef _debugopra
  Serial.println("ctlRgnAction_ZU");
  #endif
  if(!motionDisabled){
    api.octoPrintPrintHeadRelativeJog(0,0,(ctltxt*0.1),0);//x,y,z,f(speed)
  }
}

void ctlRgnAction_XL(){
  #ifdef _debugopra
  Serial.println("ctlRgnAction_XL");
  #endif
  if(!motionDisabled){
    api.octoPrintPrintHeadRelativeJog(((ctltxt*0.1)/-1),0,0,0);//x,y,z,f(speed)
  }
}

void ctlRgnAction_XYH(){
  #ifdef _debugopra
  Serial.println("ctlRgnAction_XYH");
  #endif 
  if(needsHoming()) {
    api.sendPostToOctoPrint("/api/printer/printhead","{\"command\": \"home\",\"axes\": [\"x\",\"y\",\"z\"]}");
  }else{
    api.octoPrintPrintHeadHome(); //<<< Named badly. This really homes the X and Y Axis not Z
  }
}

void ctlRgnAction_XR(){
  #ifdef _debugopra
  Serial.println("ctlRgnAction_XR");
  #endif 
  if(!motionDisabled){
    api.octoPrintPrintHeadRelativeJog((ctltxt*0.1),0,0,0);//x,y,z,f(speed)
  }
}
    
void ctlRgnAction_ZH(){
 #ifdef _debugopra
 Serial.println("ctlRgnAction_ZH"); 
 #endif
  
 if(needsHoming()) {
  api.sendPostToOctoPrint("/api/printer/printhead","{\"command\": \"home\",\"axes\": [\"x\",\"y\",\"z\"]}");
 }else{
  api.sendPostToOctoPrint("/api/printer/printhead","{\"command\": \"home\",\"axes\": [\"z\"]}"); 
 }
}
    
void ctlRgnAction_YD(){
  #ifdef _debugopra
  Serial.println("ctlRgnAction_YD");
  #endif
  if(!motionDisabled){
    api.octoPrintPrintHeadRelativeJog(0,((ctltxt*0.1)/-1),0,0);//x,y,z,f(speed)
  }
}
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

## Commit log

2022-12-24 Added Carrier board images.
2023-04-27 Added Gerber files
    [Drill_NPTH_Through.DRL, Drill_PTH_Through.DRL, Drill_PTH_Through_Via.DRL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]
2024-01-14 exposed some additional error info though serial by default.
    [Octo-Pendant.ino]
2024-01-21 Completed functionality for Filament screen. Load and unload buttons are now functional
2025-09-16 Update baud rate for more common use case. Added some extras for how to setup and sample mesh file.Added a couple of pre compiled bin files for users to get started fast.
2025-09-16 Binaries added
    A couple binaries for use with the target board. D1 Mini R1/R2
2025-09-24 added some diag print statements to help id issues related to slow calls to OctoPrint on port 80
